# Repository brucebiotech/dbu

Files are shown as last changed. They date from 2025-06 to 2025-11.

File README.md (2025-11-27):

# dbu

This project provides details on both the software and hardware for dbu, a cmsis-dap tool used for debugging ARM processors.

The dbu's main role is as a bootstrapping programmer for more complete multi-target development tools such as the [fizzit pulsar](https://github.com/brucebiotech/splice/blob/main/docs/README.md).

Based on [free-dap](https://github.com/ataradov/free-dap), dbu adds the SAML21 as a platform and introducs the capability to connect to multiple target CPU's.  A single SAML21 can support up to 6 target CPUs.

## How to use dbu

dbu is a component added to a target development board. 

```
                   Target development board
                 .-------------------------------------------------------.
                 |                       Debug target CPUs               |
                 |                                                       |          
cmsis-dap       ---.   .------.         cmsis-dap swd ports              |  
hid host        USB|---| DBU  |------+-----+-----+-----+-----+-----.     |   
adapter         ---'   |      |-.    |     |     |     |     |     |     |   
                 |     `------' |    |0    |1    |2    |3    |4    |5    |   
                 |     SWD|     |  .-+-.  -+-.  -+-.  -+-. .-+-. .-+-.   |   
bootstrap       ---.      |     |  |CPU| |CPU| |CPU| |CPU| |CPU| |CPU|   |
programming      --|------'     |  |   | |   | |   | |   | |   | |   |   |
connector       ---'            |  `-+-' `-+-' `-+-' `-+-' `-+-' `-+-'   |
                 |              |    |     |     |     |     |     |     |
                 |              `----+-----+-----+-----+-----+-----'     |
                 |                        "printf" uarts                 |
                 |                                                       |
                 `-------------------------------------------------------'
		
```
To use dbu, add a SAML21 CPU and a USB connector to your development board and provide a method of bootstrapping the dbu firmware into the SAML21. (This repository includes a low-cost edge connector based adaptor as a [bootstrap option](https://github.com/brucebiotech/dbu/blob/main/hardware/README.md#dbu-bootstrap).)

## Additional features

The dbu software also implements a cmsis-dap vendor extension to control power delivery to the target.

It also supports the cmsis-dap UART commands to tunnel a uart debug message stream over the cmsis-dap HID interface.  In other words dbu enables support for printf debugging of each target CPU over a single USB connection.

## The detail

Follow these links for more information including instructions on building the software and hardware.

[Building the software](https://github.com/brucebiotech/dbu/blob/main/software/README.md)

[Software user guide](https://github.com/brucebiotech/dbu/blob/main/docs/README.md)

[Building the hardware](https://github.com/brucebiotech/dbu/blob/main/hardware/README.md)

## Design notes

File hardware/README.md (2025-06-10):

# target hardware

The target hardware is yours to design.  It just needs to incorporate the SAML21 and botstrap programming connector somewhere, e.g as done in the [schematic](https://kicanvas.org/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) and [PCB](https://kicanvas.org/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) in the hardware folder.

```
                   Your board
                 .-------------------------------------------------------.
                 |                       Your CPUs here...               |
                 |                                                       |          
                ---.   .------.         cmsis-dap                        |  
                USB|---|SAML21|------+-----+-----+-----+-----+-----.     |   
                ---'   |      |-.    |     |                       |     |   
                 |     `------' |    |0    |1         ...          |n    |   
                 |     SWD|     |  .-+-.  -+-.                   .-+-.   |   
                ---.      |     |  |CPU| |CPU|                   |CPU|   |
                 --|------'     |  |   | |   |                   |   |   |
                ---'            |  `-+-' `-+-'                   `-+-'   |
                 |              |    |     |                       |     |
                 |              `----+-----+-----+-----+-----+-----'     |
                 |                             uarts                     |
                 `-------------------------------------------------------'
```
# dbu bootstrap

An option would be to put a standard 10-way debug pin header on the target board.  

As this connector is not used in the normal development workflow of the target, this is an example hardware for bootstrapping that saves the cost and real estate of adding the 10-pin header. 

The bootstrap dbu is connected to a traget using an edge connector on the target's PCB. The particular details of this connection are detailed as J4 on the KiCad [schematic](https://kicanvas.org/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) and [PCB](https://kicanvas.org/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) hardware files.

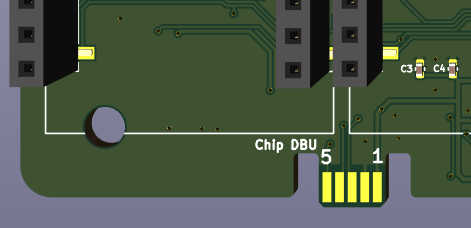
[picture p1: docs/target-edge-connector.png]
edge


You then need a second, bootstrap dbu to attach to the dbu on the target, e.g.

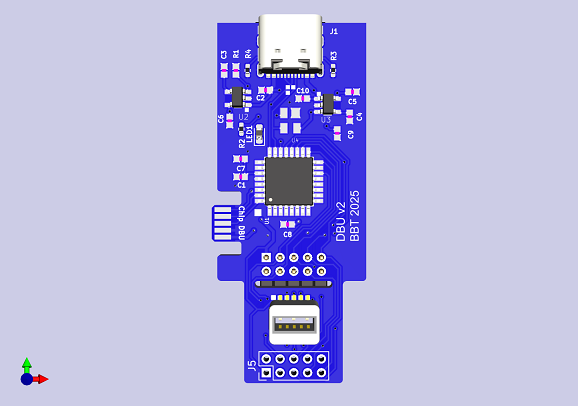
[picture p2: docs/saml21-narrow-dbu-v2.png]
PCB (https://kicanvas.org/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)


Note that this board has a break-away section for the AVX edge connector. Usually you would detach this section and connect the two parts with the 10-pin right angle pin header.

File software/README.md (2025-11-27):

# Building the dbu firmware

The firmware build uses gnu make and arm-none-eabi-gcc on linux or windows (building on windows requires msys2).

## Get the software

The easiest way to get the software is to clone this repository and goto the software directory.

## Build tools

The build requires gnu make, arm-none-eabi-gcc version 12 or later and arm-none-eabi-objcopy.

These tools should be available in the package manager for you chosen flavour of linux.  On Windows the best way to get these is to [install msys2](https://www.msys2.org/).

The makefile assumes these tools are in the path.

## Building

Select a supported dbu application name from the [makefile](https://github.com/brucebiotech/dbu/blob/main/software/platform/saml21/build/makefile).

Then use the command

```
make BOARD_NAME=<chosen board name>
```

This will generate a firmware binary dbu.elf in the application build directory ./build/<app name/dbu.elf.

Details of supported boards are in the platform Makefile.

The next step is to load this firmware into the SAML21.

## Flashing the firmware to the SAML21

Unfortunately there is no magic solution here.  You will need to use your normal default flash programming tool.

As a suggestion [EDGB](https://github.com/brucebiotech/edbg) is an easy to use cmsis-dap programmer which supports the SAML21.  This particular fork of EDBG also implements some additional functions specific to dbu described [here](https://github.com/brucebiotech/dbu/blob/main/docs/README.md).

## Roadmap

dbu currently uses HID without report numbers to be compatible with existing cmsis-dap clients (e.g. openOCD).  The drawback with this is the need to constanly [switch ports](https://github.com/brucebiotech/dbu/blob/main/docs/README.md#examples).

The version of dbu in development uses HID reports to multiplex the cmsis-dap and uart streams.  No more switching and the UART data streams become fully ascnchronous as opposed to the polled streams in the current version.

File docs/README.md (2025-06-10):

# Software User Guide

dbu provides the functionality of a standard cmsis-dap debug unit.

The caveat on this is that this is only possible on the currently selected swd port.

This is because none of the existing tools, [e.g. openOCD](#using-dbu-with-openocd) support the commands to switch the active SWD port.

dbu will power-up with port 0 active.  In order to connect debug tools to dbu on ports other than port 0, you need to use a separate port-switch application. 

## dbu specific fork of EDBG

The dbu port of [EDGB](https://github.com/brucebiotech/edbg) provides additional dbu specific command options.
```
   -get
   -set n
   -power on|off|status
```

(The uart "printf" port functions in dbu are not yet supported by edbg.)

### Examples

Get the currently selected dbu port:
```
   edbg -get -s 0 
```
will print the currently selected port for the dbu with serial number 0.

If the cmsis-dap dbug unit with serial number 0 is not a dbu then this command fails with an error message.

Set the currently selected dbu port:
```
   edbg -set 3 -s 0 
```
will set the active swd port on dbu 0 to be port 3.

### get edbg

To get the dbu specific edbg command you will need to clone [this repository](https://github.com/brucebiotech/edbg) and follow its build instructions.

These are very simple; simply run make all and you will get a small binary, called edbg.

## Using dbu with OpenOCD

Just ensure that OpenOCD is configured to use the cmsis-dap adapter driver; e.g. include the following in your openocd config:

```
adapter driver  cmsis-dap
```
By default, OpenOCD will access dbu port 0.  

To attach to other ports you need to execute an [edbg command](#examples) to switch dbu to the required port prior to starting openOCD.

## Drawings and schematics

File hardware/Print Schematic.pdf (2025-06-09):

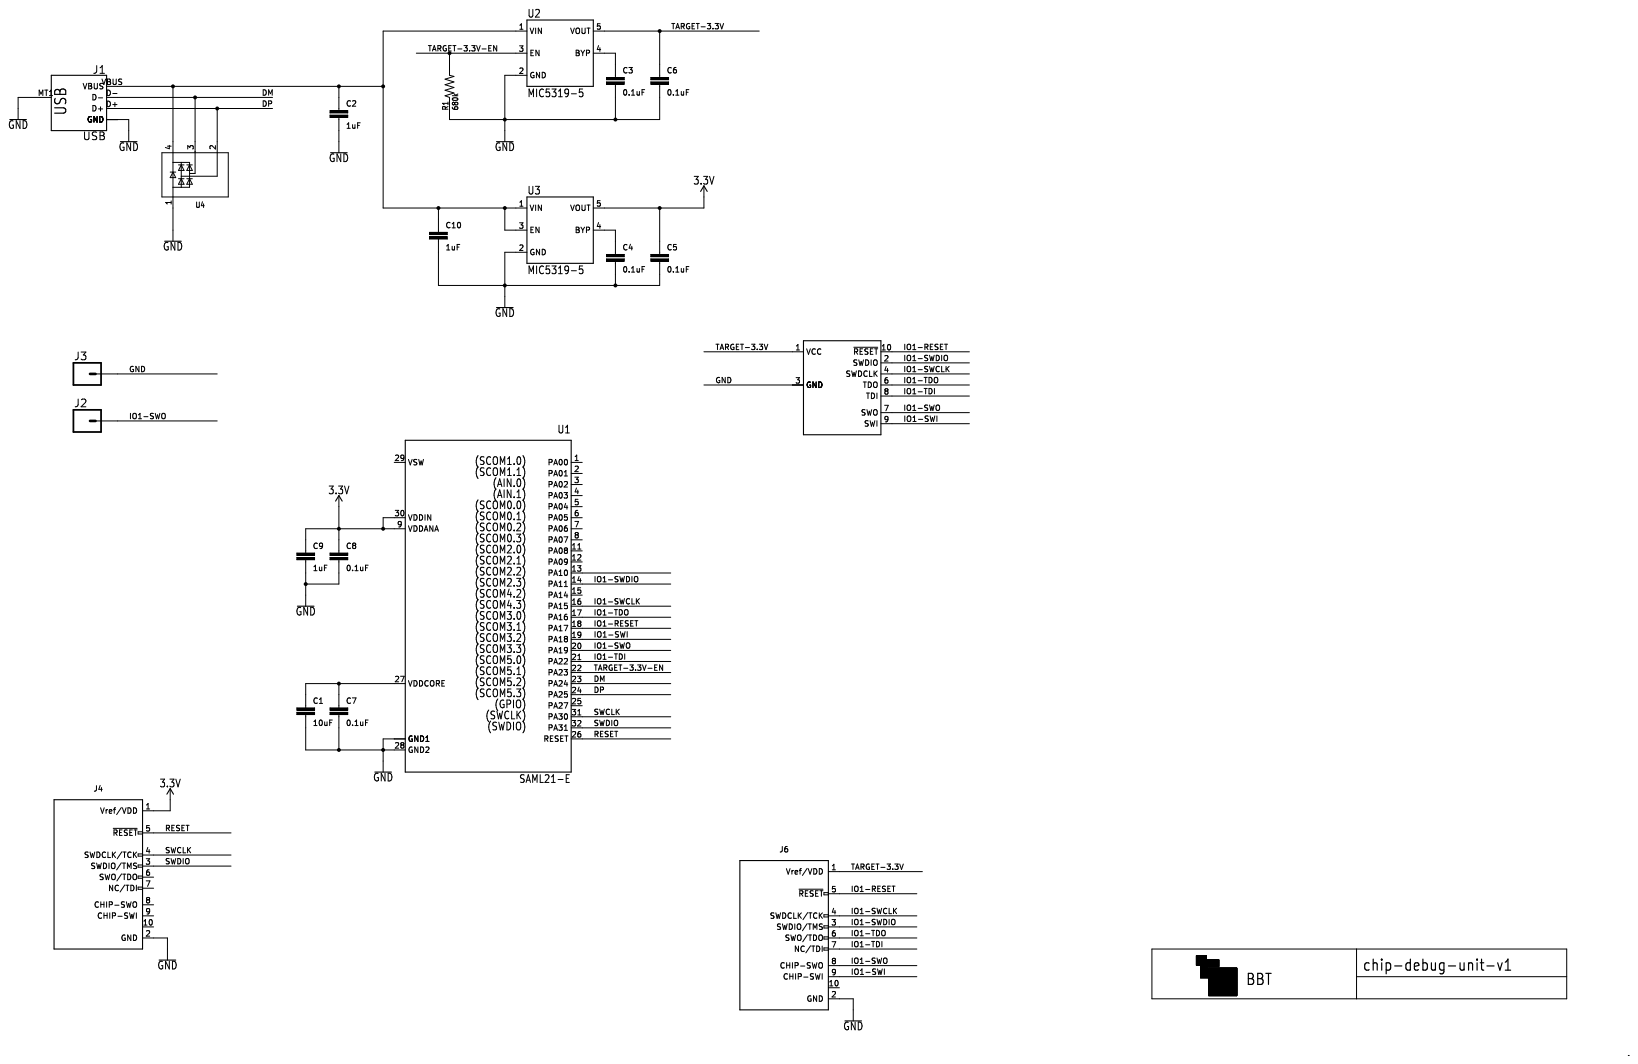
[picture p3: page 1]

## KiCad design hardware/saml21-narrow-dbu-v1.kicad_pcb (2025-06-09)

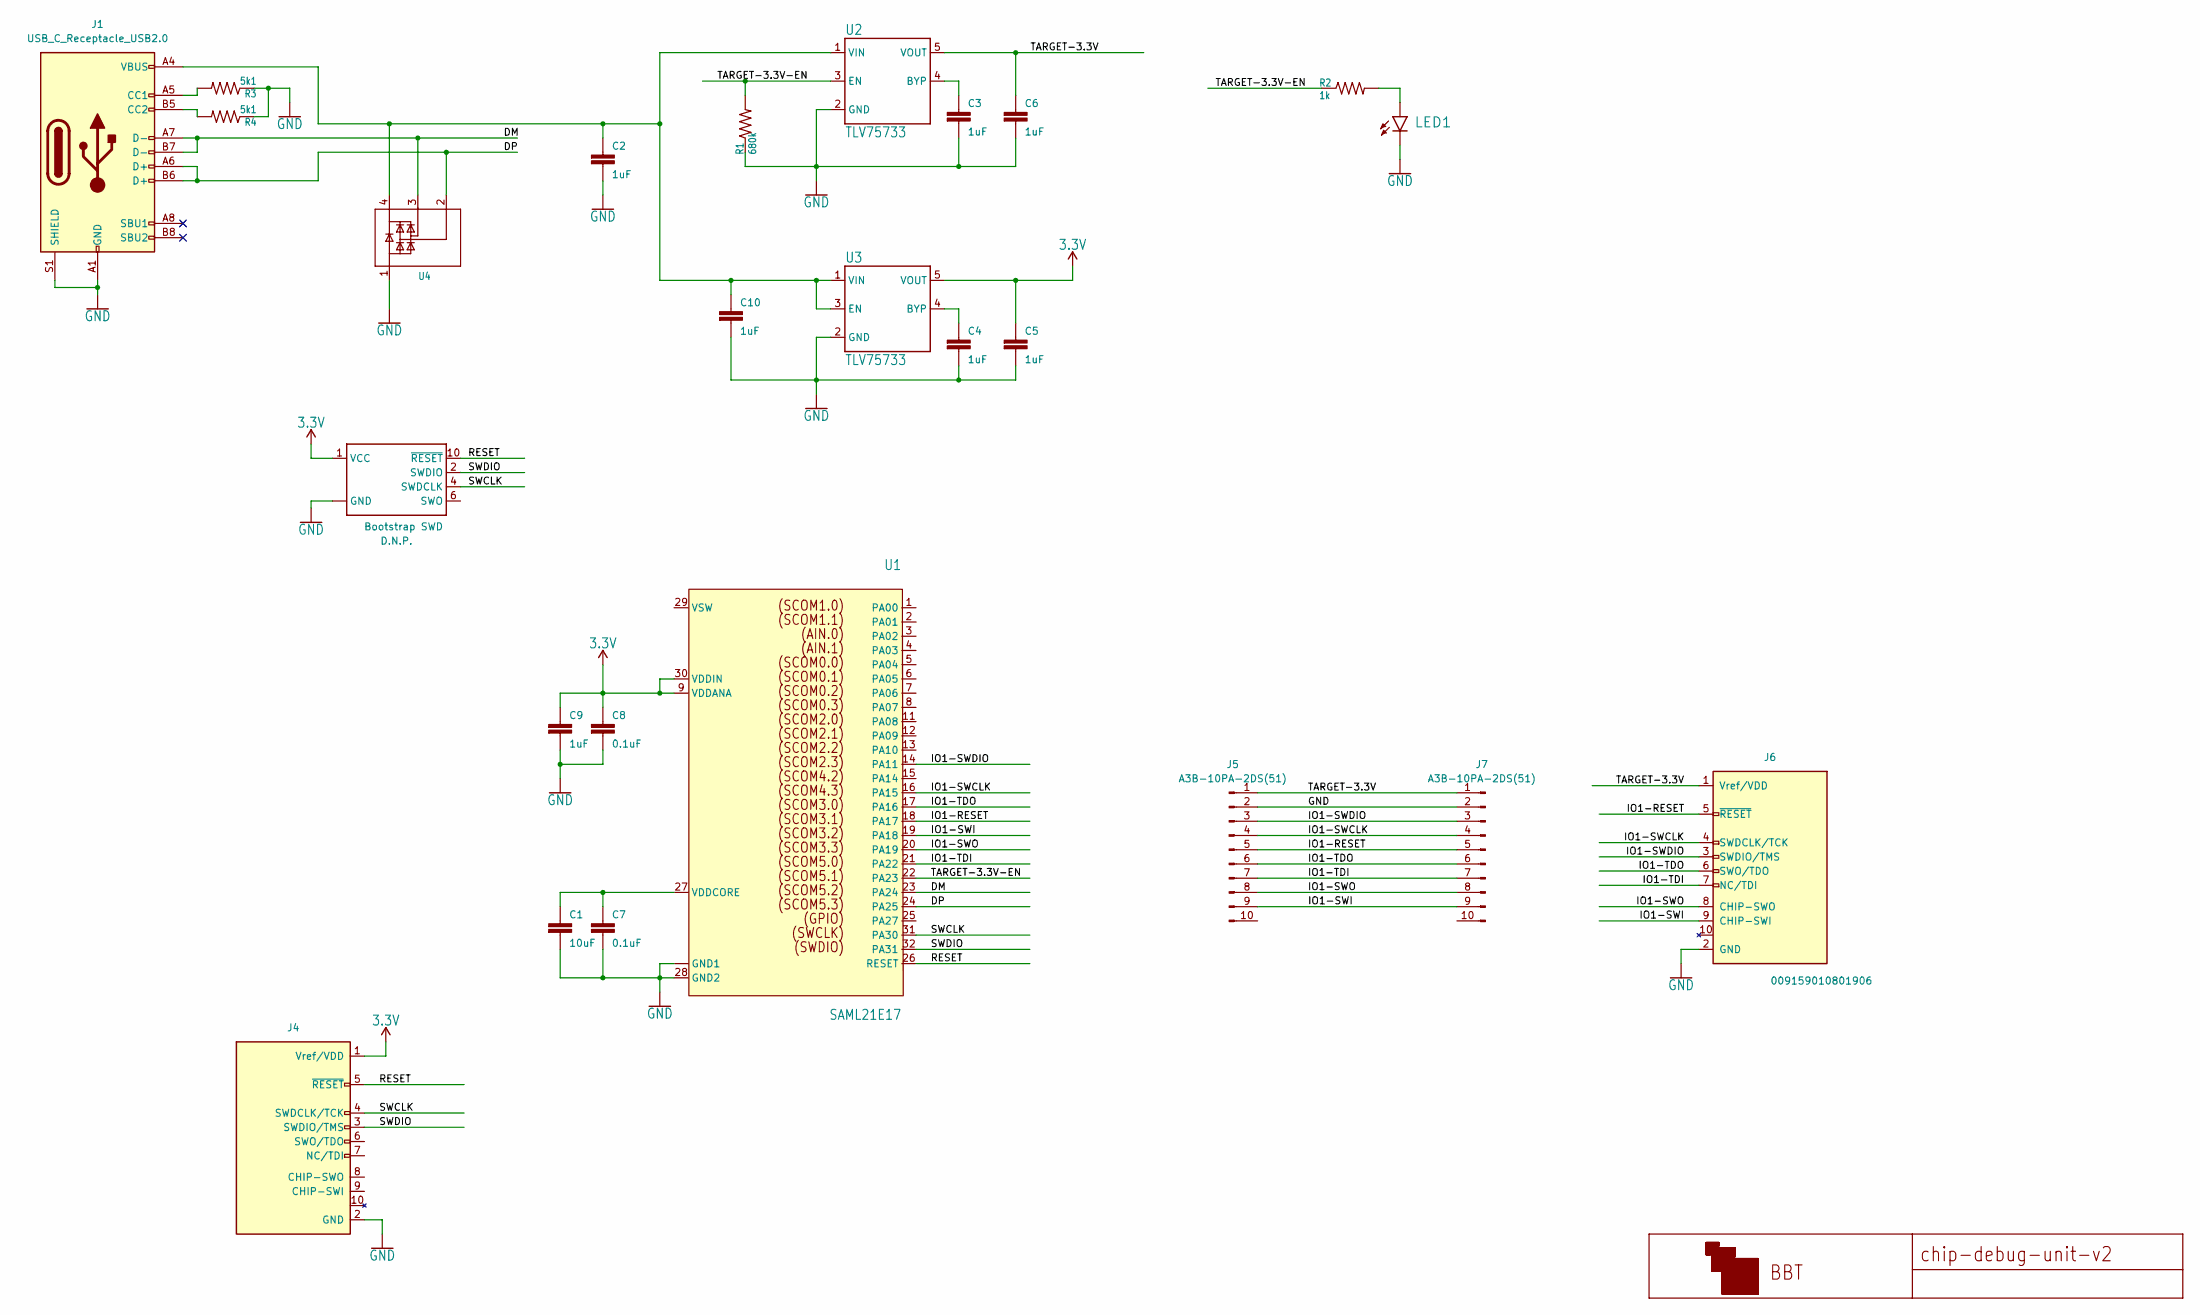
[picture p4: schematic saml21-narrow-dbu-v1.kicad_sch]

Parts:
C1: 10uF; 0402
C2, C3, C4, C5, C6, C9, C10: 1uF; 0402
C7, C8: 0.1uF; 0402
J1: USB_C_Receptacle_USB2.0; USB_C_Receptacle_GCT_USB4105-xx-A_16P_TopMnt_Horizontal
J2: Bootstrap SWD; 2X5-SMD-UNSHROUDED
J4: SWD-EDGE; blocks-edge-10-plug
J5: A3B-10PA-2DS(51); PinHeader_2x05_P2.00mm_Vertical
J6: 009159010801906; blocks-edge-10-socket; part_number 009159010801906
J7: A3B-10PA-2DS(51); PinHeader_2x05_P2.00mm_Horizontal
LED1: LED_0603_1608Metric_Pad1.05x0.95mm_HandSolder
R1: 680k; 0402
R2: 1k; R_0402_1005Metric_Pad0.72x0.64mm_HandSolder
R3, R4: 5k1; R_0402_1005Metric_Pad0.72x0.64mm_HandSolder
U1: SAML21E17; TQFP32-08
U2, U3: TLV75733; SOT23-5
U4: PRTR5V0U2-S; SOT143B

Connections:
3.3V: C5.1, C8.1, C9.1, J2.1 (VCC), J4.1 (Vref/VDD), U1.9 (VDDANA), U1.30 (VDDIN), U3.5 (VOUT)
/DM: J1.A7 (D-), J1.B7 (D-), U1.23 (PA24), U4.3
/DP: J1.A6 (D+), J1.B6 (D+), U1.24 (PA25), U4.2
/IO1-RESET: J5.5, J6.5 (~RESET), J7.5, U1.18 (PA17)
/IO1-SWCLK: J5.4, J6.4 (SWDCLK/TCK), J7.4, U1.16 (PA15)
/IO1-SWDIO: J5.3, J6.3 (SWDIO/TMS), J7.3, U1.14 (PA11)
/IO1-SWI: J5.9, J6.9 (CHIP-SWI), J7.9, U1.19 (PA18)
/IO1-SWO: J5.8, J6.8 (CHIP-SWO), J7.8, U1.20 (PA19)
/IO1-TDI: J5.7, J6.7 (NC/TDI), J7.7, U1.21 (PA22)
/IO1-TDO: J5.6, J6.6 (SWO/TDO), J7.6, U1.17 (PA16)
/RESET: J2.10 (~RESET), J4.5 (~RESET), U1.26 (RESET)
/SWCLK: J2.4 (SWDCLK), J4.4 (SWDCLK/TCK), U1.31 (PA30)
/SWDIO: J2.2 (SWDIO), J4.3 (SWDIO/TMS), U1.32 (PA31)
/TARGET-3.3V: C6.1, J5.1, J6.1 (Vref/VDD), J7.1, U2.5 (VOUT)
/TARGET-3.3V-EN: R1.2, R2.1, U1.22 (PA23), U2.3 (EN)
GND: C1.2, C2.2, C3.2, C4.2, C5.2, C6.2, C7.2, C8.2, C9.2, C10.2, J1.A1 (GND), J1.A12 (GND), J1.B1 (GND), J1.B12 (GND), J1.S1 (SHIELD), J2.3 (GND), J2.5 (GND), J2.9 (GND), J4.2 (GND), J5.2, J6.2 (GND), J7.2, LED1.C, R1.1, R3.1, R4.1, U1.10 (GND1), U1.28 (GND2), U1.EP (GND1), U2.2 (GND), U3.2 (GND), U4.1
unnamed: J1.A5 (CC1), R3.2
unnamed: J1.B5 (CC2), R4.2
unnamed: LED1.A, R2.2
unnamed: C1.1, C7.1, U1.27 (VDDCORE)
unnamed: C3.1, U2.4 (BYP)
unnamed: C2.1, C10.1, J1.A4 (VBUS), J1.A9 (VBUS), J1.B4 (VBUS), J1.B9 (VBUS), U2.1 (VIN), U3.1 (VIN), U3.3 (EN), U4.4
unnamed: C4.1, U3.4 (BYP)

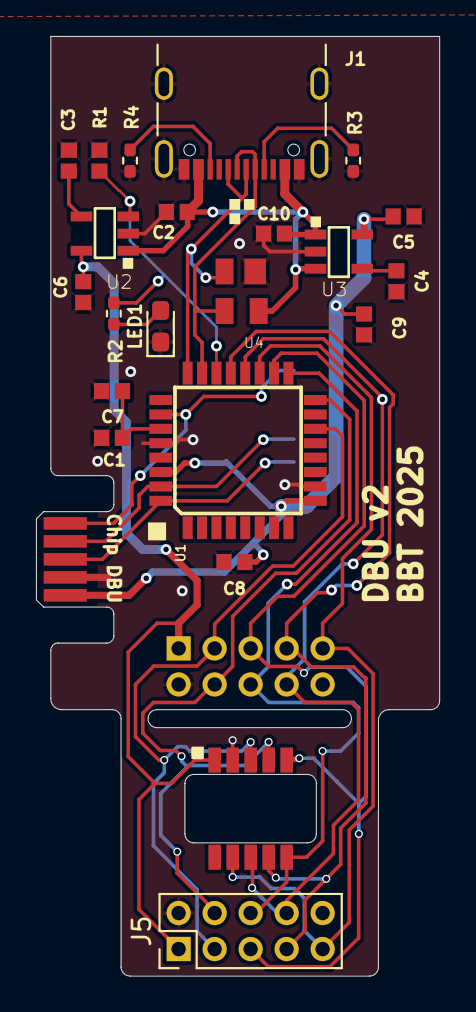
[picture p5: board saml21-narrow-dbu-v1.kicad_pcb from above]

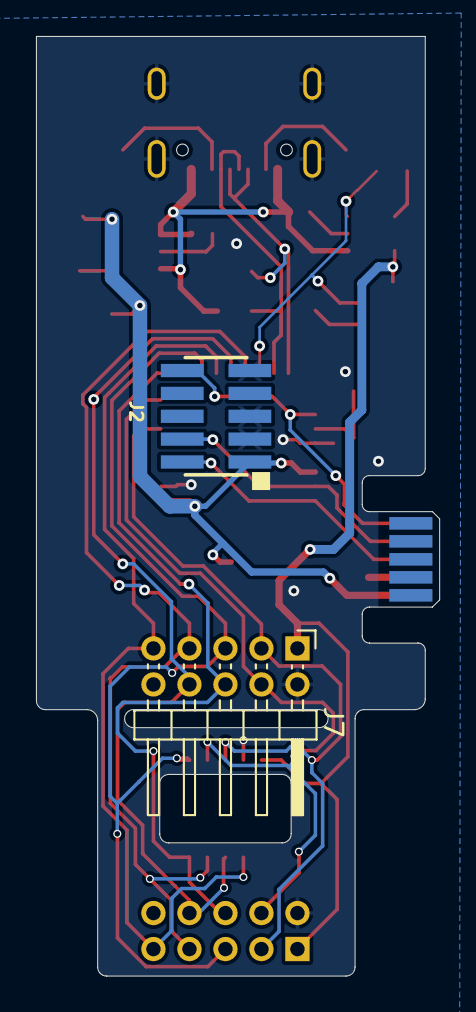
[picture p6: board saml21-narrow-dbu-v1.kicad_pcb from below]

Board: 2 copper layers, 22.4 x 52.2 mm, 25 parts (2 on the bottom side), 23 nets.

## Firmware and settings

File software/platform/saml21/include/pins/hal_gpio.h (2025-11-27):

/*
 *
 * (c) see end of file for license terms.
 *
 */
#ifndef _HAL_GPIO_H_
#define _HAL_GPIO_H_

typedef struct {
	uint8_t const *bytes;
	uint32_t size;
} byte_slice_t;

#define def_byte_slice(P,S) (byte_slice_t) {.bytes = P,.size = S}

typedef struct {
	uint8_t *bytes;
	uint32_t size;
} byte_buffer_t;

#define def_byte_buffer(P,S) (byte_buffer_t) {.bytes = P,.size = S}


#define HAL_GPIO_PORTA       0
#define HAL_GPIO_PORTB       1
#define HAL_GPIO_PORTC       2

#define HAL_GPIO_PMUX_A      0
#define HAL_GPIO_PMUX_B      1
#define HAL_GPIO_PMUX_C      2
#define HAL_GPIO_PMUX_D      3
#define HAL_GPIO_PMUX_E      4
#define HAL_GPIO_PMUX_F      5
#define HAL_GPIO_PMUX_G      6
#define HAL_GPIO_PMUX_H      7
#define HAL_GPIO_PMUX_I      8

#define PORT_PMUX_PMUXE_C PORT_PMUX_PMUXE(HAL_GPIO_PMUX_C)
#define PORT_PMUX_PMUXE_D PORT_PMUX_PMUXE(HAL_GPIO_PMUX_D)
#define PORT_PMUX_PMUXE_G PORT_PMUX_PMUXE(HAL_GPIO_PMUX_G)

#define HAL_GPIO_PIN_ACTIVE		1
#define HAL_GPIO_PIN_INACTIVE		0


#define HAL_GPIO_INLINE_FUNCTIONS(name,port,pin) \
  static inline void HAL_GPIO_##name##_set(void)				\
  {										\
    PORT->Group[HAL_GPIO_PORT##port].OUTSET.reg = (1 << pin);			\
    (void)HAL_GPIO_##name##_set;						\
  }										\
										\
  static inline void HAL_GPIO_##name##_clr(void)				\
  {										\
    PORT->Group[HAL_GPIO_PORT##port].OUTCLR.reg = (1 << pin);			\
    (void)HAL_GPIO_##name##_clr;						\
  }										\
										\
  static inline void HAL_GPIO_##name##_toggle(void)				\
  {										\
    PORT->Group[HAL_GPIO_PORT##port].OUTTGL.reg = (1 << pin);			\
    (void)HAL_GPIO_##name##_toggle;						\
  }										\
										\
  static inline void HAL_GPIO_##name##_write(int active)				\
  {										\
    if (active)									\
      PORT->Group[HAL_GPIO_PORT##port].OUTSET.reg = (1 << pin);			\
    else									\
      PORT->Group[HAL_GPIO_PORT##port].OUTCLR.reg = (1 << pin);			\
    (void)HAL_GPIO_##name##_write;						\
  }										\
										\
  static inline void HAL_GPIO_##name##_write_state(int active)				\
  {										\
    if (active ^ HAL_GPIO_##name##_active_state)									\
      PORT->Group[HAL_GPIO_PORT##port].OUTCLR.reg = (1 << pin);			\
    else									\
      PORT->Group[HAL_GPIO_PORT##port].OUTSET.reg = (1 << pin);			\
  }										\
										\
  static inline void HAL_GPIO_##name##_in(void)					\
  {										\
    PORT->Group[HAL_GPIO_PORT##port].DIRCLR.reg = (1 << pin);			\
    PORT->Group[HAL_GPIO_PORT##port].PINCFG[pin].reg |= PORT_PINCFG_INEN;	\
    PORT->Group[HAL_GPIO_PORT##port].PINCFG[pin].reg &= ~PORT_PINCFG_PULLEN;	\
    (void)HAL_GPIO_##name##_in;							\
  }										\
										\
  static inline void HAL_GPIO_##name##_out(void)				\
  {										\
    PORT->Group[HAL_GPIO_PORT##port].DIRSET.reg = (1 << pin);			\
    PORT->Group[HAL_GPIO_PORT##port].PINCFG[pin].reg |= PORT_PINCFG_INEN;	\
    (void)HAL_GPIO_##name##_out;						\
  }										\
										\
  static inline void HAL_GPIO_##name##_pullup(void)				\
  {										\
    PORT->Group[HAL_GPIO_PORT##port].OUTSET.reg = (1 << pin);			\
    PORT->Group[HAL_GPIO_PORT##port].PINCFG[pin].reg |= PORT_PINCFG_PULLEN;	\
    (void)HAL_GPIO_##name##_pullup;						\
  }										\
										\
  static inline int HAL_GPIO_##name##_read(void)				\
  {										\
    return (PORT->Group[HAL_GPIO_PORT##port].IN.reg & (1 << pin)) != 0;		\
    (void)HAL_GPIO_##name##_read;						\
  }										\
										\
  static inline int HAL_GPIO_##name##_active(void)				\
  {										\
    return ((PORT->Group[HAL_GPIO_PORT##port].IN.reg & (1 << pin)) >> pin);		\
  }										\
										\
  static inline int HAL_GPIO_##name##_state(void)				\
  {										\
    return (PORT->Group[HAL_GPIO_PORT##port].DIR.reg & (1 << pin)) != 0;	\
    (void)HAL_GPIO_##name##_state;						\
  }										\
										\
  static inline void HAL_GPIO_##name##_pmuxen(int mux)				\
  {										\
    PORT->Group[HAL_GPIO_PORT##port].PINCFG[pin].reg |= PORT_PINCFG_PMUXEN;	\
    if (pin & 1)								\
      PORT->Group[HAL_GPIO_PORT##port].PMUX[pin>>1].bit.PMUXO = mux;		\
    else									\
      PORT->Group[HAL_GPIO_PORT##port].PMUX[pin>>1].bit.PMUXE = mux;		\
    (void)HAL_GPIO_##name##_pmuxen;						\
  }										\
										\
  static inline void HAL_GPIO_##name##_pmuxdis(void)				\
  {										\
    PORT->Group[HAL_GPIO_PORT##port].PINCFG[pin].reg &= ~PORT_PINCFG_PMUXEN;	\
    (void)HAL_GPIO_##name##_pmuxdis;						\
  }								\
	/**/

#ifdef IMPLEMENT_DBU

#define HAL_GPIO_PIN(name, port, pin, active_state)						\
	const uint32_t HAL_GPIO_##name##_active_state = active_state;\
	HAL_GPIO_INLINE_FUNCTIONS (name, port, pin)\
	/**/
	
#else 

#define HAL_GPIO_PIN(name, port, pin, normal_state)						\
	extern const uint32_t HAL_GPIO_##name##_active_state;\
	HAL_GPIO_INLINE_FUNCTIONS (name, port, pin)\
	/**/
	
#endif	/* IMPLEMENT_DBU */


void initialise_sercom_uart_rx_only (Sercom *scom,IRQn_Type,uint32_t);
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

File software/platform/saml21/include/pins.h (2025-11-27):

/*
 *
 * (c) see end of file for license terms.
 *
 */
#ifndef _debug_unit_swj_pins_h_
#define _debug_unit_swj_pins_h_

#include "pins/hal_gpio.h"

enum {
	FZ1_PINS	= 0,
	FZ2_PINS,
	FZ3_PINS,
	FZ4_PINS,
	FZ5_PINS,
};

#define MAX_PIN_SETS NUMBER_OF_SWD_PORTS


typedef struct dap_connect_pin {
	void (*set) (void);
	void (*clear) (void);
	void (*in) (void);
	void (*out) (void);
	void (*write) (int);
	void (*active) (int);
	int (*read) (void);
} dap_connect_pin_t;

typedef struct dap_connect_pins {
	dap_connect_pin_t swd_sck;
	dap_connect_pin_t swd_dio;
	dap_connect_pin_t reset;
} dap_pins_t;


#if defined(BOARD_DBU_V1)
#define BOARD_HAS_TARGET_POWER
HAL_GPIO_PIN (FW_POWER_ENABLE, A, 23,  1)

HAL_GPIO_PIN (FW1_SWCLK_TCK,	A,15,  0)
HAL_GPIO_PIN (FW1_SWDIO_TMS,	A,11,  0)
HAL_GPIO_PIN (FW1_nRESET,		A,17,  0)
HAL_GPIO_PIN (FW1_LED,			A, 9,  0)

HAL_GPIO_PIN (FW2_SWCLK_TCK,	A, 3,  0)
HAL_GPIO_PIN (FW2_SWDIO_TMS,	A, 4,  0)
HAL_GPIO_PIN (FW2_nRESET,		A, 5,  0)
HAL_GPIO_PIN (FW2_LED,			A, 6,  0)

HAL_GPIO_PIN (FW3_SWCLK_TCK,	A, 3,  0)
HAL_GPIO_PIN (FW3_SWDIO_TMS,	A, 4,  0)
HAL_GPIO_PIN (FW3_nRESET,		A, 5,  0)
HAL_GPIO_PIN (FW3_LED,			A, 6,  0)

HAL_GPIO_PIN (FW4_SWCLK_TCK,	A, 3,  0)
HAL_GPIO_PIN (FW4_SWDIO_TMS,	A, 4,  0)
HAL_GPIO_PIN (FW4_nRESET,		A, 5,  0)
HAL_GPIO_PIN (FW4_LED,			A, 6,  0)

#define NUMBER_OF_SWD_PORTS	1

#elif defined(BOARD_MDU_V1) || defined(BOARD_PULSAR_V1)

HAL_GPIO_PIN (FW1_SWCLK_TCK,	B, 2,  0)
HAL_GPIO_PIN (FW1_SWDIO_TMS,	B, 3,  0)
HAL_GPIO_PIN (FW1_nRESET,		A, 2,  0)

HAL_GPIO_PIN (FW2_SWCLK_TCK,	A,10,  0)
HAL_GPIO_PIN (FW2_SWDIO_TMS,	B,10,  0)
HAL_GPIO_PIN (FW2_nRESET,		A,11,  0)

HAL_GPIO_PIN (FW3_SWCLK_TCK,	A,15,  0)
HAL_GPIO_PIN (FW3_SWDIO_TMS,	A,14,  0)
HAL_GPIO_PIN (FW3_nRESET,		B,11,  0)

HAL_GPIO_PIN (FW4_SWCLK_TCK,	A,19,  0)
HAL_GPIO_PIN (FW4_SWDIO_TMS,	A,18,  0)
HAL_GPIO_PIN (FW4_nRESET,		A,20,  0)

HAL_GPIO_PIN (FZ5_SWCLK_TCK,	A,27,  0)
HAL_GPIO_PIN (FZ5_SWDIO_TMS,	B,23,  0)
HAL_GPIO_PIN (FZ5_nRESET,		A,21,  0)

#define NUMBER_OF_SWD_PORTS	5
#define HAS_FLASH_PROGRAMMER_PORT

HAL_GPIO_PIN (FPGA_MOSI,			A, 4,  0)
HAL_GPIO_PIN (FPGA_MISO,			A, 7,  0)
HAL_GPIO_PIN (FPGA_SCK,				A, 5,  0)
HAL_GPIO_PIN (FPGA_SS,				A, 6,  0)

// dipo,dopo
#if 0
HAL_SCOM_SPI_INLINE_FUNCTIONS_C (
	FPGA,SERCOM0,PORT_PMUX_PMUXE_D,SERCOM0_IRQn,3,0
)
#else
HAL_SCOM_SPI_INLINE_FUNCTIONS_C (
	FPGA,SERCOM0,PORT_PMUX_PMUXE_D,SERCOM0_IRQn,0,2
)
#endif

HAL_GPIO_PIN (FPGA_CRESET,			B, 8,  0)
HAL_GPIO_PIN (FPGA_CDONE,			B, 9,  0)

#else
# error "need BOARD_NAME defined"
#endif

extern dap_pins_t* active_pins;
extern dap_pins_t dap_pins[];

int DUBUG_UNIT_TARGET_POWER_PIN_active ();


//
// swd sck
//	
static inline void 
DUBUG_UNIT_SWCLK_TCK_write (int value) {
	active_pins->swd_sck.write (value);
}

static inline int 
DUBUG_UNIT_SWCLK_TCK_read(void) {
	return active_pins->swd_sck.read ();
}

static inline void
DUBUG_UNIT_SWCLK_TCK_set (void) {
	active_pins->swd_sck.set ();
}

static inline void
DUBUG_UNIT_SWCLK_TCK_clr (void) {
	active_pins->swd_sck.clear ();
}

static inline void
DUBUG_UNIT_SWCLK_TCK_in (void) {
	active_pins->swd_sck.in ();
}

static inline void
DUBUG_UNIT_SWCLK_TCK_out (void) {
	active_pins->swd_sck.out ();
}

//
// swd dio
//
static inline void
DUBUG_UNIT_SWDIO_TMS_set (void) {
	active_pins->swd_dio.set ();
}

static inline void
DUBUG_UNIT_SWDIO_TMS_clr (void) {
	active_pins->swd_dio.clear ();
}

static inline void
DUBUG_UNIT_SWDIO_TMS_write (int value) {
	active_pins->swd_dio.write (value);
}

static inline int
DUBUG_UNIT_SWDIO_TMS_read (void) {
	return active_pins->swd_dio.read ();
}

static inline void
DUBUG_UNIT_SWDIO_TMS_in (void) {
	active_pins->swd_dio.in ();
}

static inline void
DUBUG_UNIT_SWDIO_TMS_out (void) {
	active_pins->swd_dio.out ();
}

//
// reset
//	
static inline void
DUBUG_UNIT_nRESET_set (void) {
	active_pins->reset.set ();
}

static inline void
DUBUG_UNIT_nRESET_clr (void) {
	active_pins->reset.clear ();
}

static inline void
DUBUG_UNIT_nRESET_write (int value) {
	active_pins->reset.write (value);
}

static inline void
DUBUG_UNIT_nRESET_active (int value) {
	active_pins->reset.active (value);
}

static inline int
DUBUG_UNIT_nRESET_read (void) {
	return active_pins->reset.read ();
}

static inline void
DUBUG_UNIT_nRESET_in (void) {
	active_pins->reset.in ();
}

static inline void
DUBUG_UNIT_nRESET_out (void) {
	active_pins->reset.out ();
}

static inline void
DUBUG_UNIT_LED (int index, int state) {
}

//-----------------------------------------------------------------------------
//
// pin ops
//	
//-----------------------------------------------------------------------------

static inline void
DUBUG_UNIT_DISCONNECT_SWJ_PINS (void) {
	DUBUG_UNIT_SWCLK_TCK_in ();
	DUBUG_UNIT_SWDIO_TMS_in ();
}

static inline void
DUBUG_UNIT_CONNECT_SWJ_PINS (void) {
	DUBUG_UNIT_SWDIO_TMS_out ();
	DUBUG_UNIT_SWDIO_TMS_set ();

	DUBUG_UNIT_SWCLK_TCK_out ();
	DUBUG_UNIT_SWCLK_TCK_set ();
}
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

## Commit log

2025-06-09 added pcb
    [saml21-narrow-dbu-v1.kicad_pcb, saml21-narrow-dbu-v1.kicad_sch]
2025-06-09 Create pcb license.txt
2025-06-09 renamed pcb dir
    [saml21-narrow-dbu-v1.kicad_pcb, saml21-narrow-dbu-v1.kicad_sch]
2025-06-10 added printf uarts
2025-09-12 fixed pin muxing
2025-11-25 removed unused boards
2025-11-25 added fizzit pulsar board

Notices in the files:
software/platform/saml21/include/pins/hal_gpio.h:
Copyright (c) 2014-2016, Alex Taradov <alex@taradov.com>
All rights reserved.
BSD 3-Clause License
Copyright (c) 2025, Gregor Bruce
